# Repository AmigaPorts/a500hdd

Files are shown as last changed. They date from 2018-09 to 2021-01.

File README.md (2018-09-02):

# Amiga 500 ATA hard disk interface

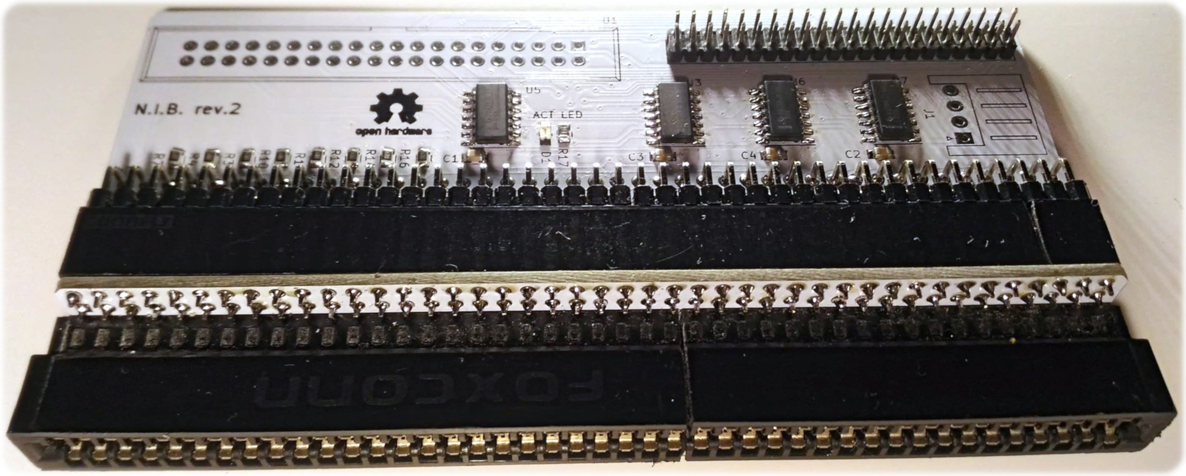
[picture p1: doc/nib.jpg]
NIB image


Floppy-bootable HDD interface for Amiga 500. Achieves 600kB/s speed on
unexpanded system. Works well with kickstart 1.3 and 2.0.

Should you have two HDD expansions mounted for same address space, you can
invert master/slave select with a set of jumpers so that both can theoretically
coexist.

This board is bundled with side expansion adapter, which converts hard-to-get
edge connector into common pin header. For user convenience and safety of
PC mainboards with ISA slots, future expansions will be developed with pin
headers as their main connector.

**NOTE:** it is strongly recommended to wait for another revision of the board
since Rev2 has some minor, but annoying bugs.

## Release structure

Binary and gerber files are only packaged in releases.
For gerbers see `board/gerber` directory.
For device/software binaries see `software/bin` and `device/bin` directories.

## Documentation

If you feel that anything here needs elaborating, feel free to submit an issue.

- [Assembly](doc/assembly.md)
- [Preparing boot floppy](doc/floppy.md)
- [Formatting HDD for Amiga use](doc/formatting.md)

## License

Project's PCB designed is licensed under Creative Commons Attribution
Share-Alike (CC BY-SA) and is based on
[a500hdd](http://nuclear.mutantstargoat.com/hw/amiga/a500hdd)
by [John Tsiombikas](mailto:nuclear@member.fsf.org).

Code is licensed under Mozilla Public License version 2 (MPL2).
Original sources are taken from TODO project by TODO and TODO.

TL;DR: You have to publish your changes under same license, marking PCB design
with notice similar to one found in this project. For code changes, each file
with MPL header you modify must be published under same license.
Sharing is caring.

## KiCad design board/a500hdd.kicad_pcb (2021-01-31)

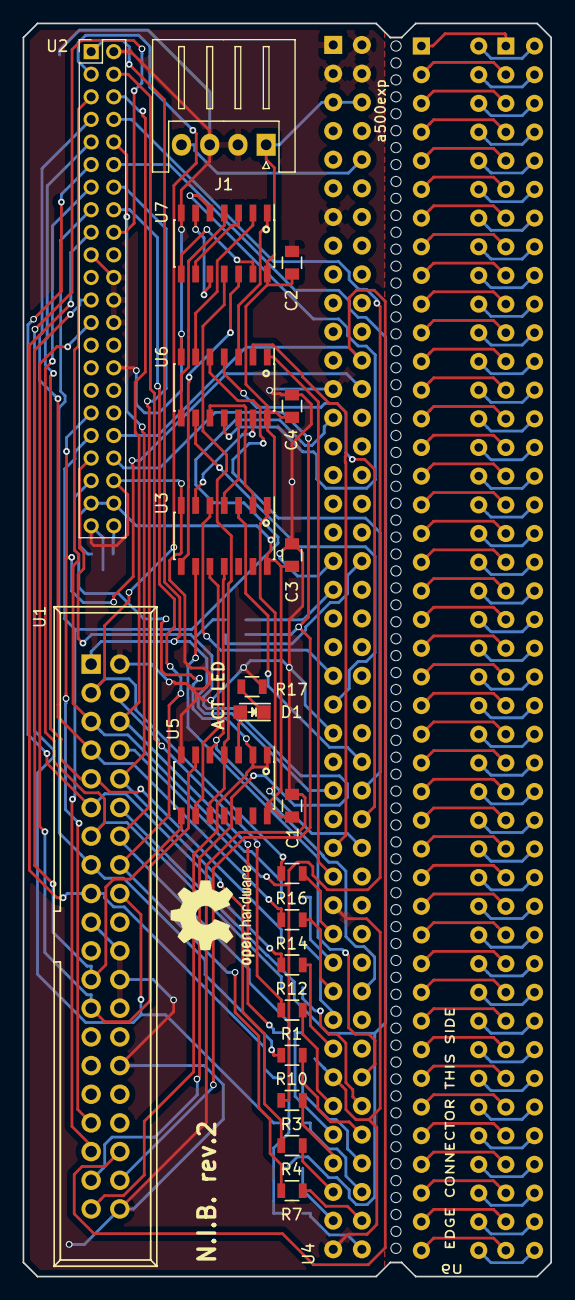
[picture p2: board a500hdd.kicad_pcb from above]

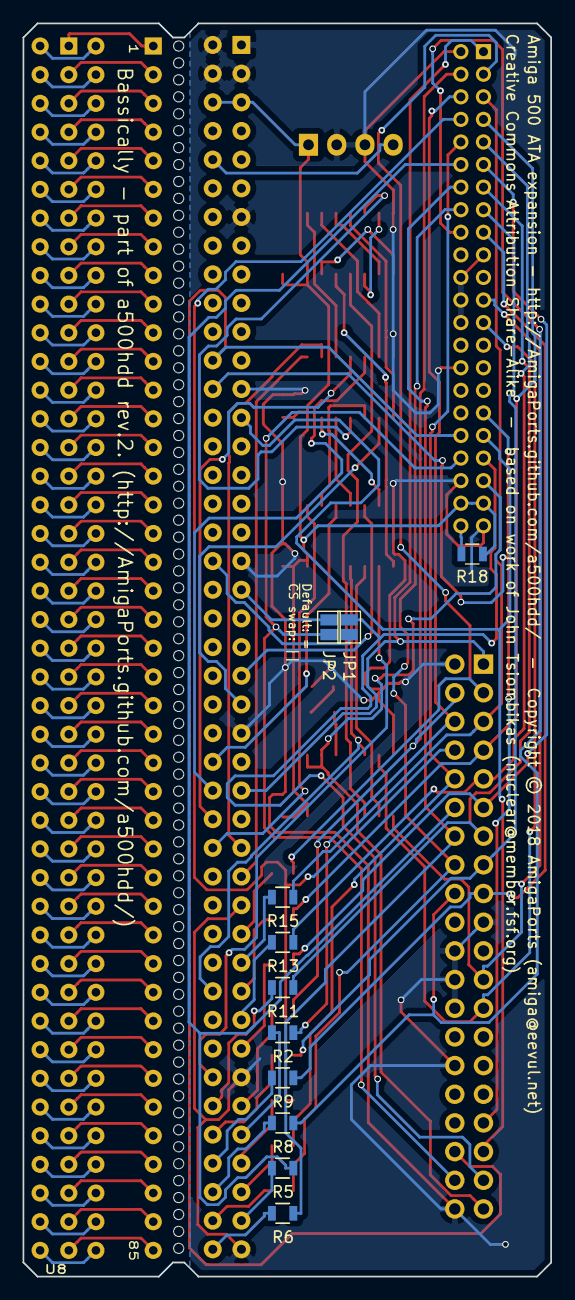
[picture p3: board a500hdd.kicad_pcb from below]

Board: 2 copper layers, 46.8 x 111.0 mm, 35 parts (11 on the bottom side), 158 nets.

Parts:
C1, C2, C3, C4: 0.1uF; C_0805
D1: LED; LED_0805
J1: Conn_01x04_Male; JST_XH_S04B-XH-A_1x04_P2.50mm_Horizontal
JP1, JP2: SolderJumper_2_Bridged; SolderJumper-2_P1.3mm_Open_Pad1.0x1.5mm
R1, R2, R3, R4, R5, R6, R7, R8, R9, R10, R11, R12, R13, R14, R15, R16: 68R; R_0805
R17: 330R; R_0805
R18: 4k7; R_0805
U1: ata_connector; IDC_Header_Straight_40pins
U2: ata_connector44; Pin_Header_Straight_2x22_Pitch2.00mm
U3: 74LS04; SOIC-14_3.9x8.7mm_Pitch1.27mm
U4, U8: a500exp; header2x43
U5: 74LS00; SOIC-14_3.9x8.7mm_Pitch1.27mm
U6, U7: 74LS08; SOIC-14_3.9x8.7mm_Pitch1.27mm
U9: a500exp; A500_Expansion_slot

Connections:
+12V: J1.4, U4.10
/D0: R1.1, U1.4, U2.4
/D1: R2.1, U1.6, U2.6
/D2: R3.1, U1.8, U2.8
/D3: R4.1, U1.10, U2.10
/D4: R5.1, U1.12, U2.12
/D5: R6.1, U1.14, U2.14
/D6: R7.1, U1.16, U2.16
/D7: R8.1, U1.18, U2.18
/D8: R9.1, U1.17, U2.17
/D9: R10.1, U1.15, U2.15
/D10: R11.1, U1.13, U2.13
/D11: R12.1, U1.11, U2.11
/D12: R13.1, U1.9, U2.9
/D13: R14.1, U1.7, U2.7
/D14: R15.1, U1.5, U2.5
/D15: R16.1, U1.3, U2.3
A16: U3.5, U4.45
A17: U4.47, U6.9
A18: U3.3, U4.52
A19: U4.54, U6.5
A20: U4.56, U6.4
A21: U3.1, U4.58
A22: U4.57, U6.2
A23: U4.59, U6.1
ATA_A0: U1.35, U2.35, U4.27
ATA_A1: U1.33, U2.33, U4.26
ATA_A2: U1.36, U2.36, U4.24
B7: U8.7, U9.7
B9: U8.9, U9.9
B11: U8.11, U9.11
B46: U8.46, U9.46
B48: U8.48, U9.48
B50: U8.50, U9.50
B51: U8.51, U9.51
B53: U8.53, U9.53
B55: U8.55, U9.55
B60: U8.60, U9.60
B61: U8.61, U9.61
B62: U8.62, U9.62
B63: U8.63, U9.63
B64: U8.64, U9.64
B65: U8.65, U9.65
B66: U8.66, U9.66
B67: U8.67, U9.67
B68: U8.68, U9.68
B69: U8.69, U9.69
B70: U8.70, U9.70
B71: U8.71, U9.71
B72: U8.72, U9.72
B73: U8.73, U9.73
B74: U8.74, U9.74
B75: U8.75, U9.75
B76: U8.76, U9.76
B77: U8.77, U9.77
B78: U8.78, U9.78
B79: U8.79, U9.79
B80: U8.80, U9.80
B81: U8.81, U9.81
B82: U8.82, U9.82
B83: U8.83, U9.83
B84: U8.84, U9.84
B85: U8.85, U9.85
B86: U8.86, U9.86
ENABLE: U5.4, U5.10, U7.11
GND: C1.2, C2.2, C3.2, C4.2, J1.2, J1.3, R17.1, U1.2, U1.19, U1.22, U1.24, U1.26, U1.30, U1.40, U2.2, U2.19, U2.22, U2.24, U2.26, U2.30, U2.40, U2.43, U3.7, U4.1, U4.2, U4.3, U4.4, U4.13, U4.25, U4.37, U4.49, U4.61, U4.73, U4.85, U5.7, U6.7, U7.7
unnamed: D1.1, R17.2
unnamed: D1.2, U5.3
unnamed: R1.2, U4.75
unnamed: R2.2, U4.77
unnamed: R3.2, U4.79
unnamed: R4.2, U4.81
unnamed: R5.2, U4.83
unnamed: R6.2, U4.86
unnamed: R7.2, U4.84
unnamed: R8.2, U4.82
unnamed: R9.2, U4.80
unnamed: R10.2, U4.78
unnamed: R11.2, U4.76
unnamed: R12.2, U4.71
unnamed: R13.2, U4.69
unnamed: R14.2, U4.67
unnamed: R15.2, U4.65
unnamed: R16.2, U4.63
unnamed: R18.1, U2.44
unnamed: U3.2, U6.10
unnamed: U3.4, U6.12
unnamed: U3.6, U6.13
unnamed: U3.8, U7.12
unnamed: U3.10, U5.9
unnamed: U6.3, U7.1
unnamed: U6.6, U7.2
unnamed: U6.8, U7.4
unnamed: U6.11, U7.5
unnamed: U7.3, U7.9
unnamed: U7.6, U7.10
unnamed: U7.8, U7.13
unnamed: U8.1, U9.1
unnamed: U8.2, U9.2
unnamed: U8.3, U9.3
unnamed: U8.4, U9.4
unnamed: U8.5, U9.5
unnamed: U8.6, U9.6
unnamed: U8.8, U9.8
unnamed: U8.10, U9.10
unnamed: U8.12, U9.12
unnamed: U8.13, U9.13
unnamed: U8.14, U9.14
unnamed: U8.15, U9.15
unnamed: U8.16, U9.16
unnamed: U8.17, U9.17
unnamed: U8.18, U9.18
unnamed: U8.19, U9.19
unnamed: U8.20, U9.20
unnamed: U8.21, U9.21
unnamed: U8.22, U9.22
unnamed: U8.23, U9.23
unnamed: U8.24, U9.24
unnamed: U8.25, U9.25
unnamed: U8.26, U9.26
unnamed: U8.27, U9.27
unnamed: U8.28, U9.28
unnamed: U8.29, U9.29
unnamed: U8.30, U9.30
unnamed: U8.31, U9.31
unnamed: U8.32, U9.32
unnamed: U8.33, U9.33
unnamed: U8.34, U9.34
unnamed: U8.35, U9.35
unnamed: U8.36, U9.36
unnamed: U8.37, U9.37
unnamed: U8.38, U9.38
unnamed: U8.39, U9.39
unnamed: U8.40, U9.40
unnamed: U8.41, U9.41
unnamed: U8.42, U9.42
unnamed: U8.43, U9.43
unnamed: U8.44, U9.44
unnamed: U8.45, U9.45
unnamed: U8.47, U9.47
unnamed: U8.49, U9.49
unnamed: U8.52, U9.52
unnamed: U8.54, U9.54
unnamed: U8.56, U9.56
unnamed: U8.57, U9.57
unnamed: U8.58, U9.58
unnamed: U8.59, U9.59
R/~W: U3.11, U4.68, U5.5
VCC: C1.1, C2.1, C3.1, C4.1, J1.1, R18.2, U2.41, U2.42, U3.14, U4.5, U4.6, U5.14, U6.14, U7.14
~AS: U3.9, U4.74
~ATA_ACTILED: U1.39, U2.39, U5.1, U5.2
~ATA_CS0: JP1.2, U1.37, U2.37
~ATA_CS1: JP2.2, U1.38, U2.38
~ATA_CSA: JP1.1, U4.38
~ATA_CSB: JP2.1, U4.39
~ATA_RD: U1.25, U2.25, U5.6
~ATA_RESET: U1.1, U2.1, U4.53
~ATA_WR: U1.23, U2.23, U5.8

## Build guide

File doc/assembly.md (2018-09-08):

# Assembling expansion

## BOM

- Expansion connector - one of the following:
  - ISA board connector - new or desoldered from old PC motherboard
  - 86-pin (2x43) straight card connector - pin raster 2.54mm (0.1"),
    rows separated by 5.08mm (0.2")
- Connection between boards:
  - 2x43 angled goldpin - or just 2x40 + 2x3 or some other combo
  - 2x43 straight goldpin socket - same as above, it's easier to get longer
    (2x50 etc.) connector and then cut it to size.
- Disk Connectors:
  - 2x20 IDC connector for ATA HDD if you want to use one
  - 4-pin power connector (like the floppy one) for ATA HDD if you want to
    use one
  - 2x22 2mm goldpin male header for ATA44 HDD if you want to use one
- Resistors (all 0805):
  - 1x: 4k7
  - 16x: 68R
  - 1x: 330R or other value for the LED of your choice
- ICs (I used `LS`, `ALS` should also work), SOT (?) package:
  - 1x: `74LS00`
  - 1x: `74LS04`
  - 2x: `74LS08`
- Capacitors:
  - 4x: 100nF, 0805
- Any 0805 LED of your choice - see "fitting LED"
- set of files - medium to fine grit
- Dremel or other cutting tool if you're using ISA connector
- Lots of patience

### Fitting LED

When you're looking for a LED to buy, you need to know two parameters:

- Forward voltage - must not be higher than 5V. Usually around 2V.
- Forward current - max is usually around 20mA.

You can find those parameters either on product page in online electronic
components store, or in datasheet which should be linked on aforementioned page.
When using datasheet, don't use values from Absolute Maximum Ratings, but range
given by min-typ-max values.

To pick proper resistor for LED, use online calculator (
  [here](http://www.hebeiltd.com.cn/?p=zz.led.resistor.calculator) or
  [here](http://ledcalc.com/) or somewhere else
) or following formula:
`R = (5-U)/I`, where U is forward voltage in volts, I is current in amps and
the result is in ohms. You most likely won't find resistor with exact value you
need, so use nearest higher one - this way there will be a bit less current
flowing thorugh LED, making it a unnoticably dimmer. You can also reduce
brightness of LED by intentionally using higher value of resistor, effectively
limiting current.

## Assembly tips & tricks

If you're combining male/female goldpin connector from two or more parts, during
soldering you can use spare corresponding connector to join two parts and ensure
they are aligned correctly.
You only need to join one row for that - removing it afterwards will be way
easier.
When joining female headers you will need to file them so that they fit
perfectly.
Work in small steps, often check if it already fits and take your time.

When soldering SMD parts, use the as thinest solder as possible - I use 0.5mm.
Here are some component-specific tricks:

- 0805 parts (resistors, capacitors, LEDs): First, apply a bit of solder on one
  of pads. Then, melt it again with your iron and use tweezers to insert one pad
  of SMD element into that pad. When everything cools off, ensure that soldered
  element is mounted properly - if it's on funny angle or something else is
  wrong, just melt solder again and correct position with tweezers. When
  everything else is ok, apply solder on remaining pad.
- for ICs you can use the same trick. First, solder element to the first or last
  pad in the row. After you're done with placement, solder IC to the most
  opposide pad (opposite row, opposide side). Then if you're right-handed,
  solder from left to right on each row.
- some people say that heating SMD capacitors only from one side produces
  thermal stresses, which may cause it to fail. I'e never had such issue,
  but you may consider soldering using solder paste and hot air gun.

## Splitting boards

There's a perforation or V-grove on board between expansion and adapter.
You need to break one board out of other. Try to put force across entire
perforation. You might the edge of your desk useful in this step.

**Rev2 note:** I've wrongly made perforations plated, and they act as
reinforcement instead of begin a weak point of board. You need Dremel or other
cutting tool to properly split them. Be sure to cut them carefully, so that you
won't damage traces on expansion board. Try to cut closer to adapter side.
Be sure to wear safety glasses because hole plating tend to break into sharp
particles flying directly into your eyes.

After boards have been split, be sure to file the edges a bit, so that loose
glass fibers won't hurt your fingers during assembly/usage. When filing the main
board, try not to damage the traces which are near the edge.

Now you should assemble expansion board and goldpin adapter in any order
as you see fit.

## Expansion board (N.I.B.)

It's best to solder side with most elements first, then the second one. Solder
pin connectors at the end. Suggested order for rev2:

- ICs
- Capacitors near them
- LED
- resistors near LED and ATA44 connetor
- 68R resistors on IC side
- secondary side
- pin connectors

Unless on the backside there's a pair of jumpers for master-slave reversal.
Unless you want to do that just solder it the default way.

## Edge-Goldpin adapter (Bassically)

Don't solder anything until you'll have all parts ready. There's lots of fitting
and trial & error at this point, so you'll want to spare yourself desoldering
mess.

That's the hardest part. If you went with ISA socket, you need to:

- Get rid of spacer between pins - use Dremel or something for that
- Remove 6 pins from either longer or shorter part you got from step above -
  I've Dremeled through 6th pin of the longer part and then filed both parts
  so that they fit nicely. Be sure to file halfway through the spacers between
  pins, so that you won't get two of them where both parts meet. Remove pins
  from inside of connector, so that your connector has both outside edges
  in their original state.
- If your connector has tiny standoffs from PCB, you may need to remove them.

TODO photo of connector:

- single spacer between pins
- shows where parts join
- outside edges neat

When you have your parts ready, you can solder things in any order you want.
I think it's best to start with goldpin socket, because after soldering edge
connector socket you won't have much room for soldering nearby pin row.
There's a note on PCB which shows on which side edge connector slot should
be placed. Goldpins should go from the other side.

**Rev2 note:** Adapter PCB has minor flaw - it works just fine but soldermask
markings orientation is wrong: labels for connector's pins 1 and 85
are in the wrong place, "EDGE CONNECTOR THIS SIDE" and other labels are upside
down, etc.

## Bugs, fixes

When using certain IDE-SD adapter, activity LED may not work properly.
This is adapter's fault and it's bugged the same way when using with A600/A1200
onboard HDD controller.

You can fix this either by modifying SD adapter or expansion itself, but I dunno
how yet. ;)

## Note on mounting female ATA44 female header

ATA44 footprint is designed so that it accepts male header.
If you want to mount female header so that you can plug IDE-SD adapter without
ribbon cable, you must resolder pins on adapter itself. Not that such
modification will render such adapter only compatible with this expansion.

Before soldering anything look at adapter's and expansion board's ATA44 pin1
(rectangular one) and notice how they should be mated so that those pins get
connected.

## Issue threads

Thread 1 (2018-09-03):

PCB adapter fixes for rev3

tehKaiN, 2018-09-03:
- [ ] Make ISA and goldpin header closer to each other
- [ ] Rotate all texts 180 degrees

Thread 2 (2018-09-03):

Investigate oktagon/oktapussy extendability

tehKaiN, 2018-09-03:
Perhaps it's possible to leave some space on PCB for mounting programmable logic and/or ROM so that this expansion could work in less hackish way and support booting

tehKaiN, 2018-12-05:
Oktagon/oktapussy is troublesome 'cuz you need programmable stuff (PLD or ROM/flash) and it makes BOM considerably pricier.

some googling has given me an info that at addr `$DE1000` there's Gayle register, and you read it like:

``` c
UBYTE ubGayle = 0;
volatile UBYTE *p = (uint16_t*)0xDE1000;
*p = 0xFF; // Write anything
for(UBYTE i = 0; i < 8; ++i) {
    ubGayle = (ubGayle << 1) | (*p >> 7);
}
logWrite("Gayle: %02X\n", ubGayle);
```

and if you expose `D0` or `D1` there with your own expansion, you'll trick kickstart into thinking that there's Gayle onboard, not Gary and it will magically boot IDE for you, probably. KS 37.300+ is needed ofc but those should be quite popular nowadays. For purists there's floppy boot option. ;)

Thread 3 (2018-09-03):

Remove plating from vias separating both boards

tehKaiN, 2018-09-03:
Plating on vias works as reinforcement instead of weakening PCB. This should not be the case.

Also, perhaps boards could be separated by edge cuts with one or two small bridges with non-plated holes for additional weakening. V-cut is an additional cost on board houses, so I'd like to avoid using them.

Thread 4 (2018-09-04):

Add fix for SD-ATA44 activity LED

tehKaiN, 2018-09-04:
some SD-ATA44 adapters wrongly produce activity signal, therefore it's not working even on A600/A1200 ATA controllers. There's a fix floating around involving soldering a transistor into adapter, but there was also a project of angled IDE adapter with single 74xx chip which fixed this signal.

- [ ] Do a research how to fix it, preferably on expansion's side
- [ ] Do a fix

tehKaiN, 2018-09-08:
Krashan fixed activity LED using dual inversion of activity signal. Schematic is [here](https://rastport.pl/produkty/KA47/). Thanks for info!

This means replacing LS04 with HCT14 and a bit of additional routing. As an added bonus I'll convert all 74xx chips to HCT family.

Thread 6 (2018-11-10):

Add clockport connections

tehKaiN, 2018-11-10:
http://www.ianstedman.co.uk/Amiga/designs/CDTV_Clockport/CDTV-Clockport.PNG

Default clockport address: **D80**000
Secondary clockport: **D84**000

But those are implemented by almost every CP expansion. 4-way expanders has also clockports on **D88**000 and **D8C**000 and those would be nice to have, since there'd limit collisions with internal expansions.

This can be implemented using 8-bit address decoder to decode **D8** on uppest address byte and feeding A15 and A14 to demux for generating 4 CS signals. Exposing two clockport connectors with CSes assignable by jumpers should suffice.

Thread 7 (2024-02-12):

Releases not found

maximevince, 2024-02-12:
The `README.md` says:

> Binary and gerber files are only packaged in releases. For gerbers see board/gerber directory. For device/software binaries see software/bin and device/bin directories.

However, no releases are to be found: https://github.com/AmigaPorts/a500hdd/releases

tehKaiN, 2024-02-12:
ah yes, they've never materialized because my gerbers used for first and only batch were kinda bad - perforations used to break boards have become metalized.

I'll try to fix it soon!

tehKaiN, 2024-02-12:
apparently I had the fix all along and even gerbers were already baked, probably did that for someone else a long time ago. No tested by me though!

maximevince, 2024-02-12:
Awesome, thanks!

Closed 2024-02-12.

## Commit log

2018-08-13 Imported sources to GitHub
    [a500hdd.kicad_pcb, a500hdd.sch]
2018-08-14 Added ATA44 header to schematic
    [a500hdd.sch]
2018-08-21 Rev2 PCB, migrated do KiCad5
    [a500hdd.kicad_pcb, a500hdd.sch]
2018-09-01 reorganized files
    [a500hdd.kicad_pcb, a500hdd.sch]
2018-09-02 added missing "Fitting LED" chapter
2018-09-08 One more capacitor is needed
2021-01-31 changed drills on board break line from PTH to NPTH
    [a500hdd.kicad_pcb]

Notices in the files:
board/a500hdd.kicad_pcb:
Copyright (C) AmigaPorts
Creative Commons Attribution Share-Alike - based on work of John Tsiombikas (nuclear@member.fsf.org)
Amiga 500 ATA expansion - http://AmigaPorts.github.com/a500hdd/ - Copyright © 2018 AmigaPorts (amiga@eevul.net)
